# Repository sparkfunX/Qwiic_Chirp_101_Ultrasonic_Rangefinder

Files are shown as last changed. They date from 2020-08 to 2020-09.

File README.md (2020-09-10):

Qwiic Chirp 101 Ultrasonic Rangefinder
========================================

Qwiic Chirp 101 Ultrasonic Rangefinder

[*Qwiic Chirp 101 Ultrasonic Rangefinder*](https://www.sparkfun.com/products/17046)

The CH101 from TDK InvenSense is a ToF (time-of-flight) ultrasonic rangefinder with a range of 4 centimeters to 1.2 meters. What sets the CH101 apart from other ultrasonic sensors that we've seen in the past is that it's capable of ranging multiple objects within its field-of-view simultaneously. This is made possible by an integrated system-on-chip that crunches the numbers and then provides digital range readings via I²C. 

Our Qwiic breakout provides voltage regulation and level shifting for the MOD-CH101 Evaluation Module. This module consists of the CH101 sensor attached to an omnidirectional acoustic housing assembly and is attached with a short flex cable for easy mounting. There is not yet an Arduino compatible library for this sensor, however there is an API and extensive documentation available from TDK. 

SparkFun labored with love to design this board. Feel like supporting open source hardware? 
Buy a [board](https://www.sparkfun.com/products/17046) from SparkFun!

Repository Contents
-------------------

* **/Hardware** - Eagle design files (.brd, .sch)
* **/Documents** - Datasheet, Programming Guides

License Information
-------------------

This product is _**open source**_! 

Please review the LICENSE.md file for license information. 

If you have any questions or concerns on licensing, please contact technical support on our [SparkFun forums](https://forum.sparkfun.com/viewforum.php?f=152).

Distributed as-is; no warranty is given.

- Your friends at SparkFun.

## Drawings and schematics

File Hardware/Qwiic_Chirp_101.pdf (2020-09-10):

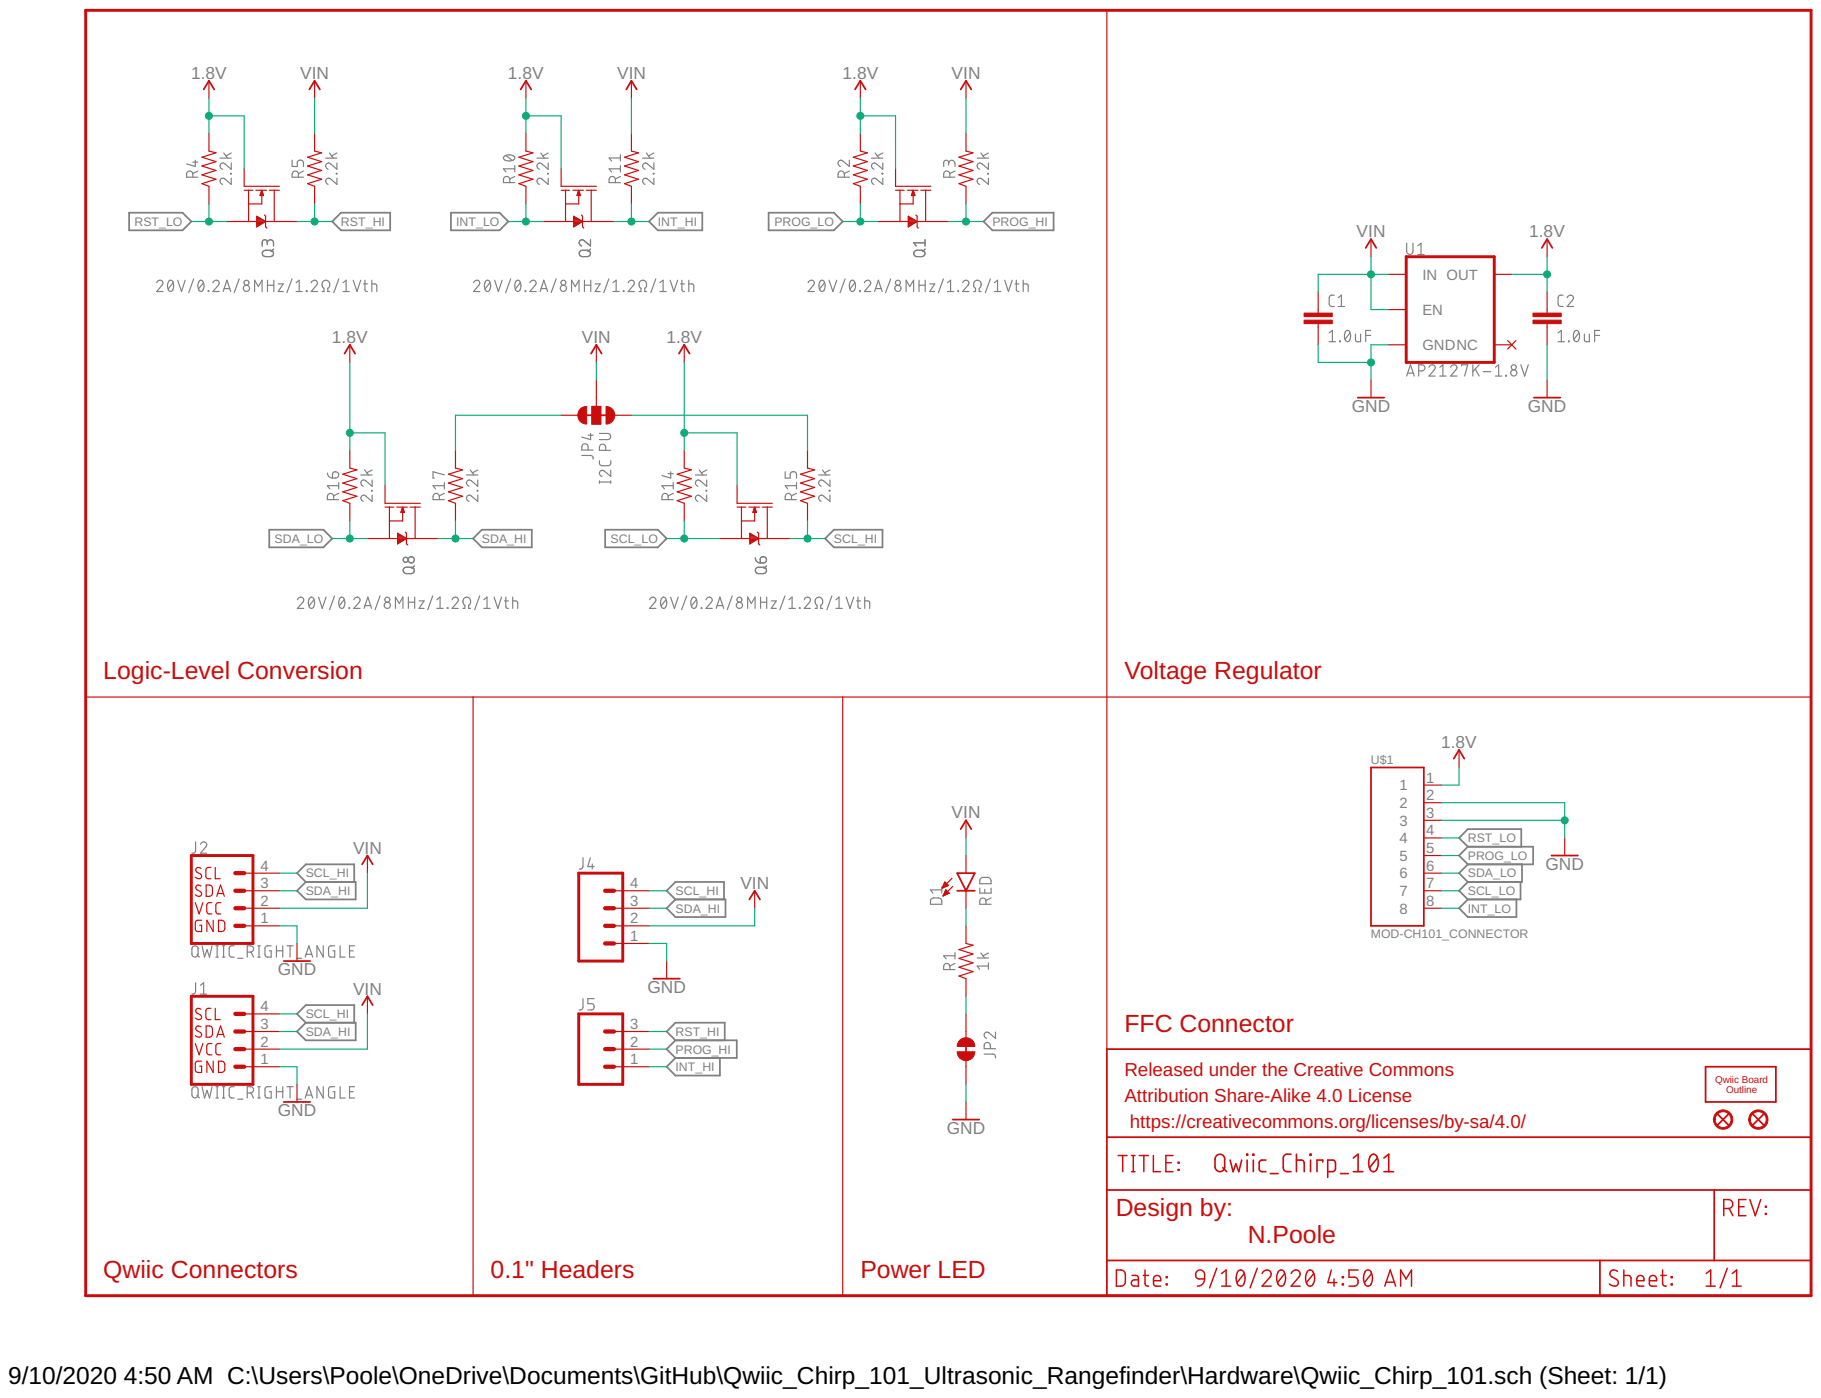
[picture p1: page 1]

Released under the Creative Commons Attribution Share-Alike 4.0 License

https://creativecommons.org/licenses/by-sa/4.0/

9/10/2020 4:50 AM C:\Users\Poole\OneDrive\Documents\GitHub\Qwiic_Chirp_101_Ultrasonic_Rangefinder\Hardware\Qwiic_Chirp_101.sch (Sheet: 1/1)

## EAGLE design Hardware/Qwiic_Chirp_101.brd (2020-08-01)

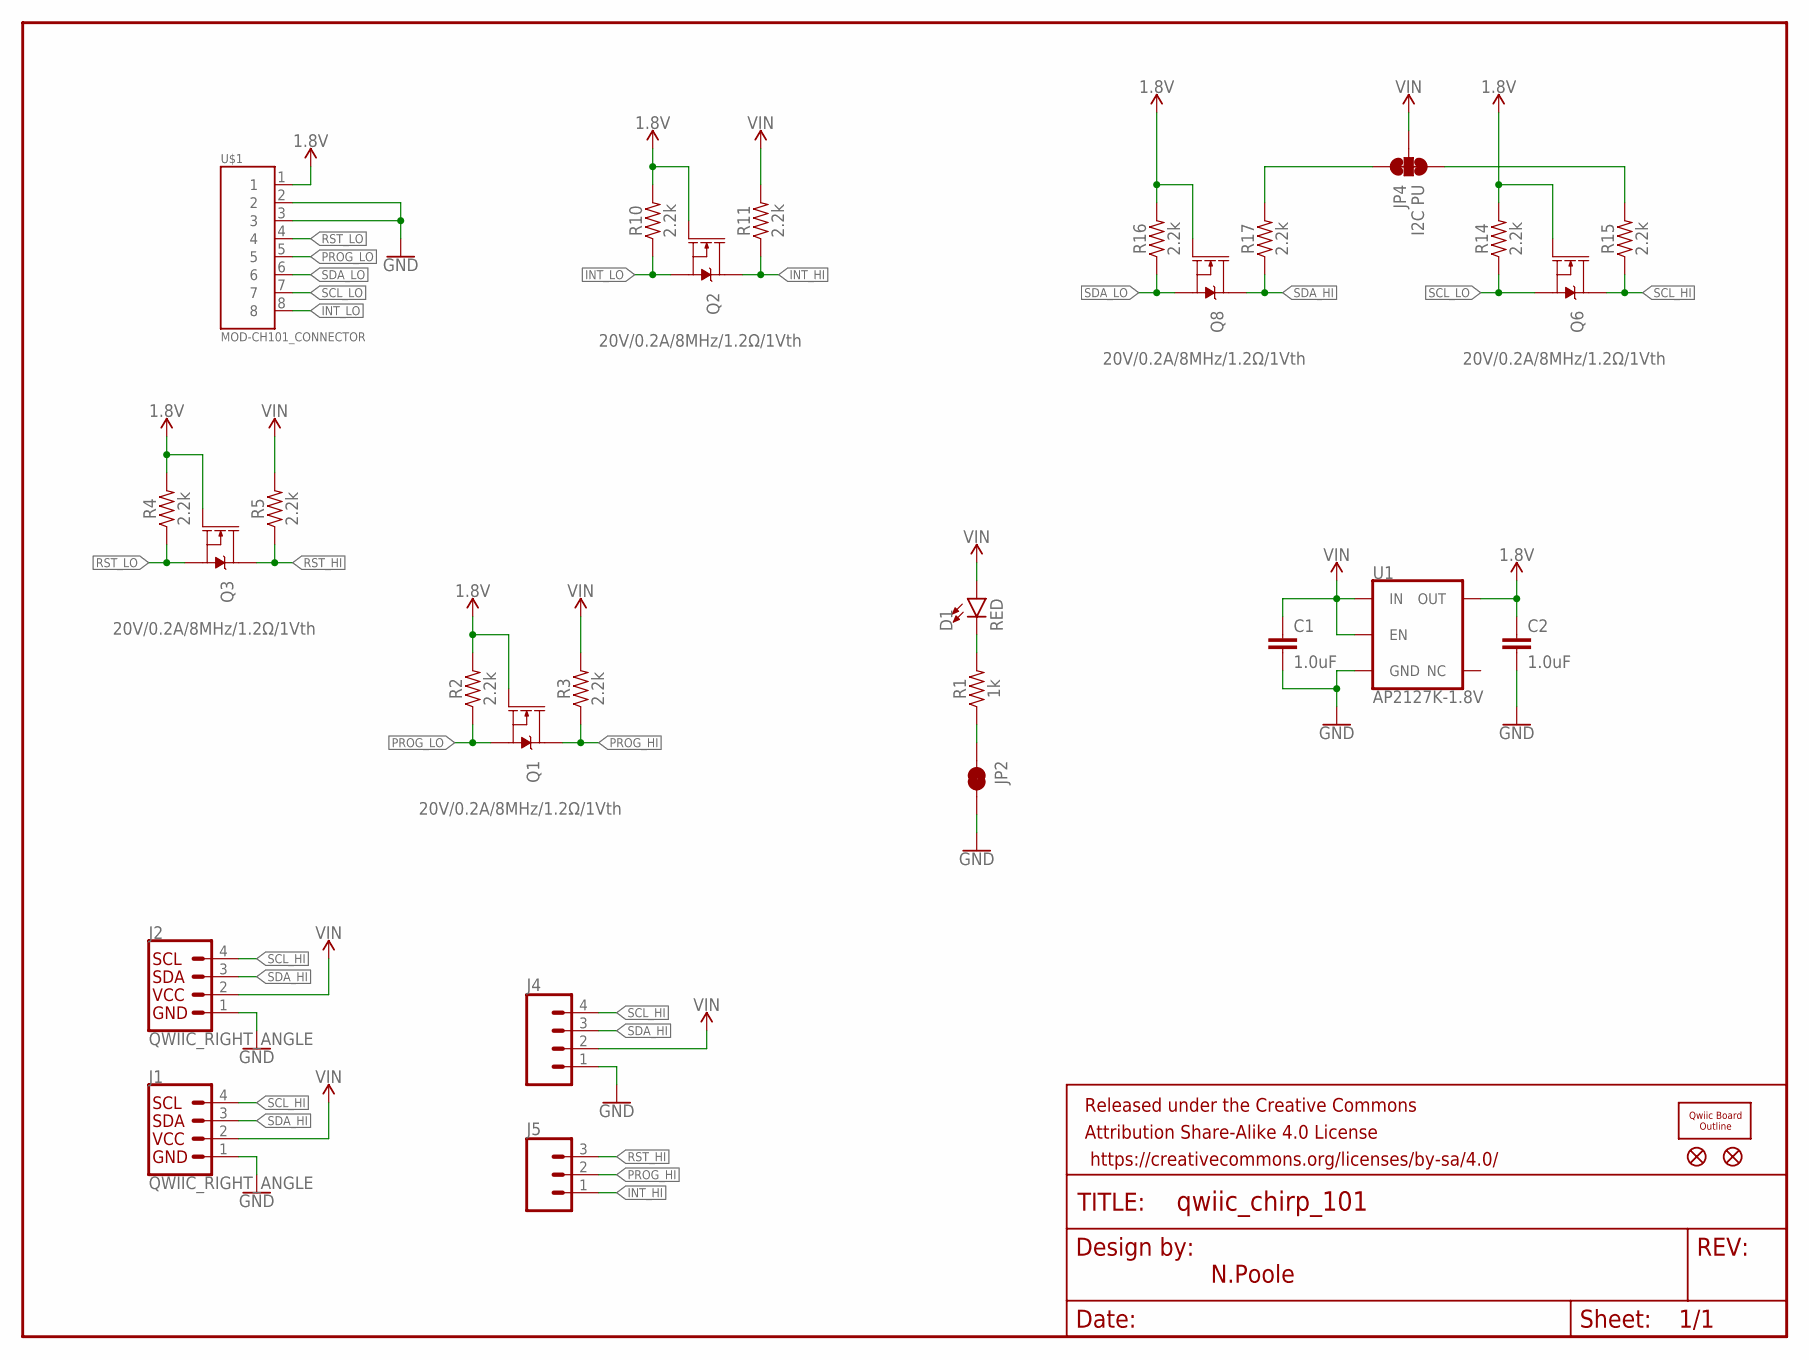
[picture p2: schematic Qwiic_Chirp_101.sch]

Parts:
C1, C2: 1.0uF; 0603
D1: RED; LED-0603
FD1, FD2: FIDUCIALUFIDUCIAL; FIDUCIAL-MICRO
FRAME1: FRAME-LETTERNO_PACKAGE; DUMMY
J1, J2: QWIIC_RIGHT_ANGLE; JST04_1MM_RA
J4: CONN_041X04_NO_SILK; 1X04_NO_SILK
J5: CONN_031X03_NO_SILK; 1X03_NO_SILK
JP2: JUMPER-SMT_2_NC_TRACE_SILK; SMT-JUMPER_2_NC_TRACE_SILK
JP4: I2C PU; SMT-JUMPER_3_2-NC_TRACE_SILK
Q1, Q2, Q3, Q6, Q8: 20V/0.2A/8MHz/1.2Ω/1Vth; SOT-416FL
R1: 1k; 0603
R2, R3, R4, R5, R10, R11, R14, R15, R16, R17: 2.2k; 0402-TIGHT
U1: AP2127K-1.8V; SOT23-5
U$1: MOD-CH101_CONNECTOR; FPC_MOLEX5034800800
U$2: QWIIC_BOARD_OUTLINEH; QWIIC_BOARD_MOUNT_HOLES

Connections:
1.8V: C2.1, Q1.1 (G), Q2.1 (G), Q3.1 (G), Q6.1 (G), Q8.1 (G), R2.2, R4.2, R10.2, R14.2, R16.2, U1.5 (OUT), U$1.1
GND: C1.2, C2.2, J1.1, J2.1, J4.1, JP2.2, U1.2 (GND), U$1.2, U$1.3
INT_HI: J5.1, Q2.3 (D), R11.1
INT_LO: Q2.2 (S), R10.1, U$1.8
unnamed: D1.C, R1.2
unnamed: JP4.3, R15.2
unnamed: JP4.1, R17.2
unnamed: JP2.1, R1.1
PROG_HI: J5.2, Q1.3 (D), R3.1
PROG_LO: Q1.2 (S), R2.1, U$1.5
RST_HI: J5.3, Q3.3 (D), R5.1
RST_LO: Q3.2 (S), R4.1, U$1.4
SCL_HI: J1.4, J2.4, J4.4, Q6.3 (D), R15.1
SCL_LO: Q6.2 (S), R14.1, U$1.7
SDA_HI: J1.3, J2.3, J4.3, Q8.3 (D), R17.1
SDA_LO: Q8.2 (S), R16.1, U$1.6
VIN: C1.1, D1.A, J1.2, J2.2, J4.2, JP4.2, R3.2, R5.2, R11.2, U1.1 (IN), U1.3 (EN)

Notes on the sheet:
N.Poole

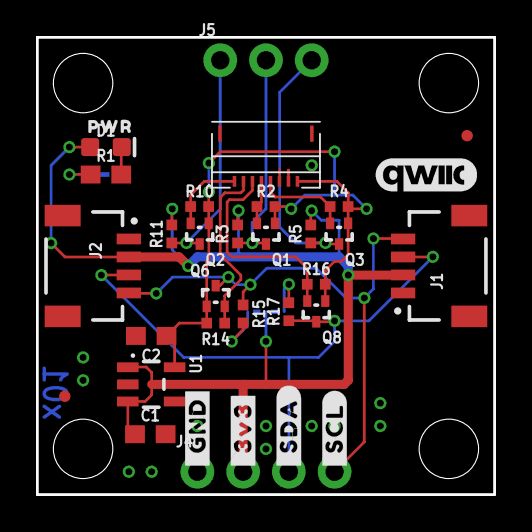
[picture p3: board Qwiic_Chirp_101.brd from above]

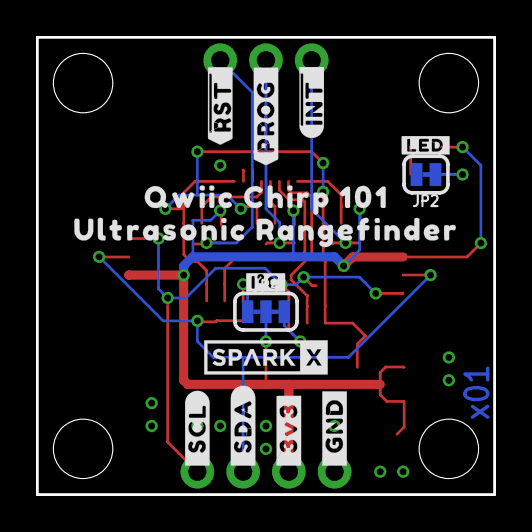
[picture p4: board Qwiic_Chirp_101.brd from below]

Board: 2 copper layers, 25.4 x 25.4 mm, 49 parts (14 on the bottom side), 17 nets.

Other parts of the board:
U$3, U$13: #_3V3#1
U$4, U$14: #_GND#0
U$5, U$12: #_SDA#2
U$6, U$11: #_SCL#3
U$7: QWIIC_CHIRP_1017
U$8: ULTRASONIC_RANGEFINDER8
U$9: #I�C#1019
U$10: #LED#1018
U$15: ##INT_##0
U$16: ##RST_##1
U$17: #PROG_#5
U$18: SPARKX-SMALL
U$19: QWIIC_COPYRIGHT_SMALL
U$20: PWR0

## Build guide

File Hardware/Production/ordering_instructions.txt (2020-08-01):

panel size, 143x136mm
PCB thickness, 1.6mm
number of layers, 2
soldermask color, Black
silkscreen color, White
oz copper, 1oz
finish, HASL lead free
stencils, top
pcs per panel, 25
min trace width, 0.1524mm / 0.0060in
min drill size, 0.3810mm / 0.0150in

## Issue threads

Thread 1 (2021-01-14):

TDH MOD_CH101 distance measurement Arduino Uno/ESP8266/ESP32 Code

amalkd, 2021-01-14:
I have TDK ultrasonic module MOD_CH101-03-02 and want to use it to measure the multiple objects distances using Arduino Uno/ESP32/ESP8266.

Please provide us the simple code which helps to interface the sensor with the microcontroller.

nseidle, 2021-01-15:
Hi - There is not yet an Arduino compatible library for this sensor, however there is an API and extensive documentation available from TDK.

jezdez, 2022-01-23:
> Hi - There is not yet an Arduino compatible library for this sensor, however there is an API and extensive documentation available from TDK.

@nseidle Hi there, could you pleas elaborate what you mean with "there is not yet an Arduino compatible library for this sensor"?

E.g. are you saying that SparkFun is working on one and it just hasn't been released yet but it's coming? Or is it a matter of the community to write (based on TDK's docs) and release one?

I'm asking since a lot of people in various forums have struggled getting this board (and chip) to run in even the most simple applications, I've yet to see one being shared publicly. And since you're still [selling the Qwiic board](https://www.sparkfun.com/products/17046), I was trying to understand what I can expect. Same is true for the relatively [new SMT version of it](https://www.sparkfun.com/products/17271), right?

Your clarification would definitely help, thank you!

jezdez, 2022-01-24:
> Howdy! SparkFun is not currently working on a library nor do we currently plan to for the MOD-CH101 or the SMD version of the CH101. I welcome any collaboration or PR! We have so many other fun projects currently at play; it would be some time before the CH101 got high enough on the list for us to tackle an Arduino wrapper for TDK's API.

Awesome, thank you for the clarification, totally understood! 🙌🏻

Closed 2021-01-15.

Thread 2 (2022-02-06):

Hi, Is there a working API example to use over SPI?

omer-arad, 2022-02-06:
Or any code samples we can use?
We are tying to integrate this sensor but having difficulties.

Thanks!

RudyFiero, 2022-02-06:
Have you looked the documentation at https://invensense.tdk.com/products/dk-ch101/

I had looked at these sensors more than a year ago. They couldn't do what I wanted so I abandoned the project. I was using their kit. From what I remember, this was a real pain in the ass part to use.

omer-arad, 2022-02-06:
Yes, it has no examples or documentation on how to relay the sensor readings via any communication method.
I'm looking for a working example I can take a deeper look at.

sriccardi-invn, 2024-04-08:
Hi,
TDK published official Arduino Driver for Chirp ultrasound Sensor.
This is available natively in Arduino IDE in library manager.
Regards,
Seb

NaveenKoyyada, 2024-07-31:
Hi,
Iam also working on ch101 for nRF chip, I hardly ported the code and tested but some I2C call is getting failed (error: -5).
I tested with esp32 using arduino library, it is also not worked.

Anyone tried with Arduino library, will it work?

sriccardi-invn, 2024-07-31:
HI,
My name is Sebastien Riccardi, I am Senior director at TDK and my team provided Chirp Sensor Arduino driver.
CH101 sensor support only I2C. New ICU family support only SPI.
Could you describe which HW you are using with which SW Package and version ?
Regards,
Sebastien Riccardi

NaveenKoyyada, 2024-07-31:
Hi Sebastien,
The library version is
ch101_gpr_version = "gpr_gpr-101_v47";
SonicLib API/Driver version = 4.2.1

And the sensor part number is EV_MOD_CH101-01-02.

sriccardi-invn, 2024-07-31:
HI @NaveenKoyyada ,
Thanks for detail.
Have you try an example through Arduino IDE?
Could you descrive wiring between nrf board and EV_MOD_CH101-01-02 and share sensor init logic analyzer traces?
Regards,
Seb

NaveenKoyyada, 2024-08-01:
Hi @sriccardi-invn ,
Our HW team designed a level shifter, circuit diagram
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
.
Initially I tried with Arduino, but the sensor initialization is getting failed. So moved to interface with nRF which is the main MCU of my project.
I will probe and share the images shortly.

regards,
Naveen

NaveenKoyyada, 2024-08-01:
Hi @sriccardi-invn ,
Thanks for your patience.
Is the above level shifter ckt is ok?, the part number of level shifter used for INT is 74AVCH4T245PW-Q10J.

I can only share the digital scope images. please find them below
PROG pin at 1.8v
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
Reset pin at 1.8v
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
SCL at 1.8v
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
SDA at 1.8v
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

After debugging, I can observe that it is failing at Loading RAM
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

Thanks&Regards,
Naveen

rbuisson-invn, 2024-08-01:
Hello Naveen,

Could you please check the maximum number of bytes supported in a single I2C write access by your hardware (usually linked to the I2C FIFO depth)?
During device programming the library tries to write a huge number of bytes in a single write access, assuming that the HAL will manage/split in multiple transfer depending on max I2C transmit length.
If it appears that the transfer length is too big, you will have to modify your HAL to split the write accesses in multiple smaller write segments (of supported length), using I2C restart after each segment, such as:
Start | Adress+write bit | segment0 | Restart | segment1 | Restart | segment2 | Stop

Please let us know the status,
Regards

NaveenKoyyada, 2024-08-01:
Okay I will go through the nRF library to find out this.
Meanwhile, I have couple of questions running in my mind from few days.
1. Is there anything like soniclib software version supports particular ch101[suffix] part number?
2. I am currently using SonicLib API/Driver v4.2.1 and ch101_gpr_version is gpr_gpr-101_v47, Is it a working library and sensor part number is EV_MOD_CH101-01-02?
3. I have observed different ram init address and size in ch101_gpr_fw file for soniclib version 4.2.1 and 3.24.0, why there is difference in the firmware and how its related to sensor HW?

Thanks for the support.
Let me get back to you once I confirm with the I2C transfer bytes.
Regards,
Naveen

rbuisson-invn, 2024-08-01:
1. The SonicLib supports CH101 and CH102 among other TDK ultrasound sensors
2. Version v4.2.1 is the latest validated version and it comes with gpr v47, so all good.
3. You are correct the I2C address for firmware programming is different than the regular one.

Regards,

NaveenKoyyada, 2024-08-01:
Hi @rbuisson-invn ,
Thanks for the clarification.
I just printed how many bytes of transfer call is happening, please see below log
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
For loading RAM, first call is of 3bytes(address is 1byte and 2bytes of data) but still I2C is getting failed.

Regards,
Naveen

rbuisson-invn, 2024-08-01:
Thanks for checking @NaveenKoyyada !
I checked the library source code, and these values are expected.
So far, I don't understand how it could fail, while previous write at same address are correctly responded.

Could you please double check the following basic things:
- you are actually using a CH101 part (for which the ch101_gpr firmware is designed)
- the I2C address that you set for the device in chbsp_i2c_get_info is different than the programming address (0x45)
- as the previous operation is an I2C read, could you please check that the STOP condition is correctly emitted on I2C line.

Do you have any idea of the meaning of the error code "err -5" from the I2C HAL, it does not look like a nRF error code? It might be helpful to get nRF error.

Regards,

rbuisson-invn, 2024-08-01:
It seems that some Nordic devices have issues with clock streching (see https://infocenter.nordicsemi.com/index.jsp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).
As CH101 uses clock streching it might be useful to look at I2C signals for the the failing writes).

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

NaveenKoyyada, 2024-08-02:
Hi @rbuisson-invn
Please find my reply for your previous message.
you are actually using a CH101 part (for which the ch101_gpr firmware is designed)
ANS: Yes, I rechecked the ch_init. I selected "ch101_gpr_init" which points to "ch101_gpr_fw_text " in ch101 firmware file.
the I2C address that you set for the device in chbsp_i2c_get_info is different than the programming address (0x45)
ANS: I didn't define chbsp_i2c_get_info struct. Verified the address 0x45 on each I2C call from library.
as the previous operation is an I2C read, could you please check that the STOP condition is correctly emitted on I2C line.
ANS: Yes, I checked.

I just debugged the initial I2C failure in loading ram.
I observed that the ram parameters in below image
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
if you see the ram init address is 512 and size is 38. When I analyze chdrv_prog_write(), in the first I2C call, the 512 is passed as data and address is 0x05(which further add with 0x80). But when read these values, its giving different values, maybe is this giving issue for failure? Or I have to consider different API for this I2C call.
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

For soniclib version 3.24.0, the ram address is 2420 and size is 13. Will both versions work with same sensor?

Regards,
Naveen

NaveenKoyyada, 2024-08-02:
> HI, My name is Sebastien Riccardi, I am Senior director at TDK and my team provided Chirp Sensor Arduino driver. CH101 sensor support only I2C. New ICU family support only SPI. Could you describe which HW you are using with which SW Package and version ? Regards, Sebastien Riccardi

Hi @sriccardi-invn ,
Did you get any chance to review my reply messages?
Regards,
@NaveenKoyyada

NaveenKoyyada, 2024-08-03:
Hi @rbuisson-invn ,
Is there any update?
Br,
Naveen

sriccardi-invn, 2024-08-05:
Hi @NaveenKoyyada ,
Remi is OOO today. He will update you tomorrow.
Regards,
Seb

rbuisson-invn, 2024-08-06:
Hello @NaveenKoyyada ,

Thanks for your answers.
Regarding "you are actually using a CH101 part" question, my point was to confirm that the hardware part that you are using is actually a CH101 (and not a CH201 for instance, which could explain the issue).

If you take a look to chdrv_prog_mem_write implementation, you'll see that the first step to write memory is to set the address register:
		ch_err = chdrv_prog_write(dev_ptr, CH_PROG_REG_ADDR, addr);
This call will issue a write to I2C device 0x45, at address 0x05 (i.e. 0x85 with write bit), and 512 (0x200) for the data (LSB first).
This is what I actually see in your trace: 0x85, 0x00, 0x02.

For some reason, your HAL detect an error and returns -5.

To progress on this debug, you could do the following:
1. Confirm that your hardware is actually a CH101 and not CH201
2. Check or share the source code of your HAL, to get the meaning of the -5 error code.
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
rbuisson-invn, 2024-08-16:
Hello Naveen,

RTC calibration is done by the MCU sending a pulse on IT line, waiting 100ms (MCU time) and then sending a second pulse.
This lets the device calibrate its clock using this 100ms delay as a reference.
So basically, the dependencies are I2C communication, INT pin driving, and the MCU delay.
The reference HW (Ultrasonic ToF EVK board) uses a level shifter with a dedicated pin to control the direction, if you're using same kind of level shifter you'll need an additional pin control.

Regards,

NaveenKoyyada, 2024-08-16:
Thanks for the information let me check
Br
Naveen

rbuisson-invn, 2024-08-19:
Hello Naveen,

To correct a bit what I said in my previous message: the RTC calibration is performed using a 100ms pulse in the INT1 line (NOT with 2 pulses), as in following picture.
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

Regards,

NaveenKoyyada, 2024-08-21:
Hi @rbuisson-invn ,
The frequency lock is not happening, the  mem_read is getting failed.
After repeat testing, the sensor is working till the use of device address 0x45 and when application address 0x29/0x2d is called the sensor is not reachable.
log:
[00:00:00.518,829] <inf> ch_driver:
                                    chdrv_group_prepare:0

[00:00:00.518,859] <inf> ch_driver:
                                    chbsp_i2c_init:0

[00:00:00.525,604] <inf> ch_driver: Test I2C read: 020A
[00:00:00.525,634] <inf> ch_driver: Device [0] found on bus
[00:00:00.526,214] <inf> ch_driver: PROG_STAT: 0x05
[00:00:00.531,646] <inf> ch_driver: Loading RAM OK

[00:00:00.762,451] <inf> ch_driver: Wrote 2026 bytes in 122187 ms.
[00:00:00.762,451] <inf> ch_driver: Firmware write OK

[00:00:00.763,275] <inf> ch_driver: Changing I2C address to 0x29
[00:00:00.779,418] <inf> ch_driver: ch101 sensor detected

[00:00:00.779,449] <inf> ch_driver: Sensor count: 1, 261addr:0x29 mem_addr:0x14

[00:00:00.779,693] <err> chbsp_chirp: chbsp_i2c_mem_read 1bytes failed from addr:0x14 err:-5

[00:00:00.789,794] <inf> ch_driver: chdrv_wait_for_lock:10

[00:00:00.789,825] <inf> chbsp_chirp: chbsp_i2c_mem_read i2c_addr:0x29 mem_addr:0x14

[00:00:00.790,008] <err> chbsp_chirp: chbsp_i2c_mem_read 1bytes failed from addr:0x14 err:-5

[00:00:00.800,109] <inf> ch_driver: chdrv_wait_for_lock:21

[00:00:00.800,140]
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

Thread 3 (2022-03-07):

Here is an example for ch101 from nuboton

kylongmu, 2022-03-07:
[https://www.nuvoton.com.cn/products/microcontrollers/arm-cortex-m23-mcus/m261-m262-m263-series/m263kiaae/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](url)

sriccardi-invn, 2024-04-08:
Hi,
TDK published official Arduino Driver for Chirp ultrasound Sensor.
This is available natively in Arduino IDE in library manager.
Regards,
Seb

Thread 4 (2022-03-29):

HW issue with INT level shifter

rprzybyla-invn, 2022-03-29:
My name is Richard Przybyla and I’m the Principal (Team lead) for System Engineering team for TDK-Invensense Ultrasonic Time Of Flight sensors. I am also a co-founder of Chirp Microsystems.

I am writing you about the two PCBs you have designed for CH101. I wanted to thank you for designing a breakout board for CH101. This can be a very valuable tool. However, these boards  are not correctly designed.
- Qwiic Chirp 101 Ultrasonic Rangefinder - SPX-17046 - SparkFun Electronics
- Qwiic Chirp 101 Ultrasonic Rangefinder SMT - SPX-17271 - SparkFun Electronics

The issue is related to the INT signal voltage shifter that doesn’t work correctly.
As indicated in the CH101 datasheet the INT operates as a bidirectional I/O with a high-side common drain output (CH101 datasheet page 14). It implies that the configuration used in “Qwiic Chirp 101” boards doesn’t work.

We have received complains about CH101 device from some customers. After our investigation, we discovered that the issues are related to your Qwiic Chirp 101 Ultrasonic Rangefinder - SPX-17046 - SparkFun Electronics board. These customers rely on your board to implement a level shifter, but the board doesn’t work.

I have few requests:
1.	Please remove the current version of the Qwiic boards from your website and github and stop distributing them to Mouser, Digikey, etc.

2.	If you plan to redesign the board, please refer to the document in attachment. The document is an portion of an Application Note that will be soon published on TDK-Invensense web site. In the document is described as implement correctly the INT signal level shifter.

3.	Qwiic Chirp 101 Ultrasonic Rangefinder SMT - SPX-17271 - SparkFun Electronics board - please note that a plastic horn has to be mounted on top of the chip. I would like to ask you to add a note in the document list that clearly indicate this point indicating the application note AN-000158-CH101-Mechanical-Integration-Guide-v1.1.pdf (netdna-ssl.com) to find additional information.

My wish is that Sparkfun will redesign the boards and release the fixed version soon. I am available to assist with this if needed.

Looking forward to receive good news from your side. Thanks, Richie

[AN-000259 CH101_Design_Guide v1.2.pdf](https://github.com/sparkfunX/Qwiic_Chirp_101_Ultrasonic_Rangefinder/files/8375450/AN-000259.CH101_Design_Guide.v1.2.pdf)

nseidle, 2022-03-30:
Hi Richie - Thanks for opening up an issue and I appreciate the willingness to help. My apologies for the problematic INT interface. Both boards will be discontinued once stock is exhausted.

I've added "See the [Mechanical Integration Guide](https://cdn.sparkfun.com/assets/a/3/7/4/2/AN-000158-CH101-Mechanical-Integration-Guide-v1.1.pdf) for more information." to the CH101 description and docs tab.

It's rare that we hear directly from sensor manufacturers. The CH101 is a really interesting technology. We have heaps of feedback and recommendations to improve the user experience. If you have technologies or sensors that you need help with in the future, please let us know.

I'm going to leave this issue open so that other viewers of the repo can easily find it.

rprzybyla-invn, 2022-03-30:
Hi Nathan,

Thanks a lot for your reply.

Yes, we are always grateful for feedback. I will DM you my contact info.

We have also recently announced a new generation of our ultrasonic transceivers: https://invensense.tdk.com/smartsonic/. These ones have built in level shifters for 3.3V I/O. Hope you can design a breakout board for those when they are ready for distribution. And should you decide to take on a redesign of the breakout for CH101/CH201, please let me know if we can help or review your design.

samograsic, 2023-02-27:
Hi Richard.
I am trying to get the data from the EV_MOD_CH101-01-02 development sensor. After reading I2C address 0x29 I am getting the 0xFFFF value. What I am wondering is if the sensor comes with any default firmware loaded or do I need to purchase the development board and upload firmware first?

rprzybyla-invn, 2023-02-27:
Hi Samo,
No, the CH101 does not contain any firmware (or any nonvolatile memory to store it on). Our driver loads the FW during initialization every time you power up the sensor. Our driver example is available to run on our Smartsonic DK board, but you can port it to your own board by implementing your own board support package.

To port to another platform, you need to implement the low level functions defined in
\SmartSonic_HelloChirp_v1.31.0\source\drivers\chirpmicro\inc\chirp_bsp.h, following the extensive guidelines and documentation provided in this file.
The particular implementation that is used for Smartsonic is available here:
\SmartSonic_HelloChirp_v1.31.0\source\board\HAL\src\chbsp_chirp_samg55.c

And the example itself is available on the website (on the CH101 webpage https://invensense.tdk.com/products/ch101/):
https://invensense.tdk.com/developers/wp-content/uploads/sites/2/2021/08/SmartSonic_HelloChirp_Example_v1_31_0.zip

sriccardi-invn, 2024-04-08:
Hi,
TDK published official Arduino Driver for Chirp ultrasound Sensor.
This is available natively in Arduino IDE in library manager.
Regards,
Seb

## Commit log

2020-08-01 x01 panelized for production
    [8_POS_0_5MM_PITCH_40MM_LENGTH.brd, Qwiic_Chirp_101-Panel.brd, Qwiic_Chirp_101.brd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]
2020-08-02 x01 ordered
    [8_POS_0_5MM_PITCH_40MM_LENGTH.brd]
2020-08-19 I dunno
    [Qwiic_Chirp_101.csv]
2020-09-10 Cleaning up schematic
    [Qwiic_Chirp_101.csv, Qwiic_Chirp_101.sch]

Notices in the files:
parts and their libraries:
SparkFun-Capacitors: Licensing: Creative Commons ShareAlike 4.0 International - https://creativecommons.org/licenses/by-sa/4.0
